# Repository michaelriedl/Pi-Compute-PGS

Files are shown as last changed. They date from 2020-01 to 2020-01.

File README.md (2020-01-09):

# Pi-Compute-PGS
Portable gaming system based on the Raspberry Pi Compute module

I took this project as far as I possibly could but ran out of steam. I figured I would open source it so other people can take it up if they like. The major revisions I was facing are as follows:

1. The buttons need to be moved further away from the screen.
I designed the board independent of designing the enclosure which was a huge mistake. There is not enough clearance around the screen to accomodate a correctly sized button.
2. I ordered the wrong battery IC and ended up frying a prototype board trying to simultaneosy play and charge the PGS.
3. Stereo out
4. HDMI out
5. On-board WiFi

This board was designed in a 4.x version of KiCad and has not been updated to 5.0+ so I'm not sure how it will behave.

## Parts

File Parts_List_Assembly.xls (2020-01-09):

Sub-Assembly | Description | Part | Value | Package | Quantity | Link | Footprint Checked
Pi Compute Module | SODIMM | A114854-ND | - | - | 1 | http://www.digikey.com/product-detail/en/te-connectivity-amp-connectors/1473149-4/A114854-ND/1890696 | Yes
 | Resistor |  | 100k | 0402 | 5 | http://www.digikey.com/product-detail/en/panasonic-electronic-components/ERJ-2RKF1003X/P100KLCT-ND/194127 | Yes
 | Capacitor |  | 4.7uF | 0603 | 2 | http://www.digikey.com/product-detail/en/samsung-electro-mechanics-america-inc/CL10B475KQ8NQNC/1276-2087-1-ND/3890173 | Yes
 | uSD Card Slot | WM6357CT-ND | - | - | 1 | http://www.digikey.com/product-detail/en/molex-llc/1040310811/WM6357CT-ND/2804769 | Yes
 | Micro USB |  | - | - | 1 | http://www.digikey.com/product-detail/en/amphenol-fci/10103594-0001LF/609-4050-1-ND/2350357 | Yes
Power Supplies | Fuse | MF-MSMF200-2CT-ND | 2A | - | 1 | http://www.digikey.com/product-detail/en/bourns-inc/MF-MSMF200-2/MF-MSMF200-2CT-ND/662850 | Yes
 | Capacitor |  | 47uF | 1206 | 6 | http://www.digikey.com/product-detail/en/murata-electronics-north-america/GRM31CR60J476KE19L/490-6508-1-ND/3845705 | Yes
 | Capacitor |  | 100nF | 0402 | 2 | http://www.digikey.com/product-detail/en/kemet/C0402C104K9RACTU/399-4872-1-ND/1090867 | Yes
 | Capacitor |  | 10uF | 0805 | 4 | http://www.digikey.com/product-detail/en/murata-electronics-north-america/GRM219R60J106KE19D/490-3340-1-ND/702881 | Yes
 | Capacitor |  | 1uF | 0402 | 3 | http://www.digikey.com/product-detail/en/taiyo-yuden/JMK105BJ105KV-F/587-1231-1-ND/931008 | Yes
 | Capacitor |  | 4.7uF | 0603 | 1 | http://www.digikey.com/product-detail/en/samsung-electro-mechanics-america-inc/CL10B475KQ8NQNC/1276-2087-1-ND/3890173 | Yes
 | Resistor |  | 0R | 0402 | 2 | http://www.digikey.com/product-detail/en/panasonic-electronic-components/ERJ-2GE0R00X/P0.0JCT-ND/146726 | Yes
 | Resistor |  | 100k | 0402 | 1 | http://www.digikey.com/product-detail/en/panasonic-electronic-components/ERJ-2RKF1003X/P100KLCT-ND/194127 | Yes
 | Inductor |  | 4.7uH 2A | - | 2 | http://www.digikey.com/product-detail/en/bourns-inc/SRN4018-4R7M/SRN4018-4R7MCT-ND/3821520 | Yes
 | Micro USB |  | - | - | 1 | http://www.digikey.com/product-detail/en/amphenol-fci/10103594-0001LF/609-4050-1-ND/2350357 | Yes
 | 3v3 and 1v8 Regul | PAM2306AYPKE | - | - | 1 | http://www.mouser.com/ProductDetail/Diodes-Incorporated/PAM2306AYPKE/?qs=QK%2FAlAnD7r6vC0KF37wC2Q%3D%3D | Yes
 | 2v5 Regul | AP7115-25SEG-7 | - | - | 1 | http://www.mouser.com/ProductDetail/Diodes-Incorporated/AP7115-25SEG-7/?qs=oUsD4qhOtFzl3uIiEMdYbQ%3D%3D | Yes
Screen and Connector | LCD Screen | NHD-4.3-480272EF-ATXL#-ND | - | - | 1 | http://www.digikey.com/product-detail/en/newhaven-display-intl/NHD-4.3-480272EF-ATXL-/NHD-4.3-480272EF-ATXL--ND/3597747 | Yes
 | 40 Pin Connector | WM3431CT-ND | - | - | 1 | http://www.digikey.com/product-detail/en/molex-llc/0541044031/WM3431CT-ND/2405801 | Yes
 | Resistor Array |  | 33R | 1206 | 7 | http://www.digikey.com/product-detail/en/bourns-inc/CAY16-33R0F4LF/CAY16-33R0F4LFDKR-ND/5775070 | Yes
 | Resistor |  | 10k | 0805 | 2 | http://www.digikey.com/product-detail/en/yageo/RC0805FR-0710KL/311-10.0KCRCT-ND/730482 | Yes
 | Resistor |  | 12R | 0805 | 1 | http://www.digikey.com/product-detail/en/yageo/RC0805FR-0712RL/311-12.0CRCT-ND/730514 | Yes
 | Capacitor |  | 10uF | 0805 | 1 | http://www.digikey.com/product-detail/en/murata-electronics-north-america/GRM219R60J106KE19D/490-3340-1-ND/702881 | Yes
 | Capacitor |  | 1uF | 0402 | 2 | http://www.digikey.com/product-detail/en/taiyo-yuden/JMK105BJ105KV-F/587-1231-1-ND/931008 | Yes
 | Capacitor |  | 100nF | 0402 | 1 | http://www.digikey.com/product-detail/en/kemet/C0402C104K9RACTU/399-4872-1-ND/1090867 | Yes
 | Inductor | BRL3225T150K | - | - | 1 | http://www.digikey.com/product-detail/en/taiyo-yuden/BRL3225T150K/587-3027-1-ND/2763398 | Yes
 | Diode | MBR0540 | - | - | 1 | http://www.digikey.com/product-detail/en/fairchild-on-semiconductor/MBR0540/MBR0540CT-ND/3042807 | Yes
 | Diode | SMAZ24-TP | - | - | 1 | https://www.digikey.com/product-detail/en/micro-commercial-co/SMAZ24-TP/SMAZ24-TPMSCT-ND/1636198 | Yes
 | LED Regul | FAN5333BSX | - | - | 1 | http://www.digikey.com/product-detail/en/fairchild-on-semiconductor/FAN5333BSX/FAN5333BSXCT-ND/3042778 | Yes
Game Pad | Right Ang Tact SW |  | - | - | 2 | https://www.digikey.com/product-detail/en/apem-inc/MJTP1117/679-2400-ND/1795496 | Yes
 | Tact SW |  | - | - | 3 | https://www.digikey.com/product-detail/en/e-switch/TL3315NF100Q/EG4620CT-ND/1870400 | Yes
 | Dome SW |  | - | - | 8 | https://www.digikey.com/product-detail/en/keystone-electronics/5133TR/36-5133CT-ND/6834345 | Yes
 | Resistor |  | 10k | 0805 | 13 | http://www.digikey.com/product-detail/en/yageo/RC0805FR-0710KL/311-10.0KCRCT-ND/730482 | Yes
 | Resistor |  | 1k | 0805 | 13 | http://www.digikey.com/product-detail/en/yageo/RC0805FR-071KL/311-1.00KCRCT-ND/730391 | Yes
Battery Management | Charging Controller | MCP73871 | - | - | 1 | https://www.digikey.com/product-detail/en/microchip-technology/MCP73871-2CCI-ML/MCP73871-2CCI-ML-ND/1680971 | Yes
 | Voltage Booster | TPS61090RSAR | - | - | 1 | https://www.digikey.com/product-detail/en/texas-instruments/TPS61090RSAR/296-15259-1-ND/566899 | Yes
 | Capacitor |  | 10uF | 0805 | 2 | http://www.digikey.com/product-detail/en/murata-electronics-north-america/GRM219R60J106KE19D/490-3340-1-ND/702881
 | Capacitor |  | 100nF | 0402 | 1 | http://www.digikey.com/product-detail/en/kemet/C0402C104K9RACTU/399-4872-1-ND/1090867
 | Capacitor |  | 2.2uF | 0603 | 1 | https://www.digikey.com/product-detail/en/yageo/CC0603KRX5R5BB225/311-1449-1-ND/2833755
 | Electrolytic Capacitor |  | 100uF | 1411 | 1 | https://www.digikey.com/product-detail/en/avx-corporation/F930J107KBA/478-8153-1-ND/4005595 | Yes
 | Resistor |  | 1.87M | 0805 | 2 | https://www.digikey.com/product-detail/en/panasonic-electronic-components/ERJ-6ENF1874V/P1.87BTCT-ND/4429149
 | Resistor |  | 340k | 0805 | 1 | https://www.digikey.com/product-detail/en/yageo/RC0805FR-07340KL/311-340KCRCT-ND/730822
 | Resistor |  | 200k | 0805 | 1 | https://www.digikey.com/product-detail/en/yageo/RC0805FR-07200KL/311-200KCRCT-ND/730671
 | Resistor |  | 1k | 0805 | 5 | http://www.digikey.com/product-detail/en/yageo/RC0805FR-071KL/311-1.00KCRCT-ND/730391
 | Resistor |  | 270k | 0805 | 1 | https://www.digikey.com/product-detail/en/yageo/RC0805FR-07270KL/311-270KCRCT-ND/730731
 | Resistor |  | 100k | 0402 | 2 | http://www.digikey.com/product-detail/en/panasonic-electronic-components/ERJ-2RKF1003X/P100KLCT-ND/194127
 | Resistor |  | 15k | 0805 | 1 | https://www.digikey.com/product-detail/en/yageo/RC0805FR-0715KL/311-15.0KCRCT-ND/730555
 | Inductor | ASPI-0615FS-6R8M-T2 | 6.8uH | - | 1 | https://www.digikey.com/product-detail/en/abracon-llc/ASPI-0615FS-6R8M-T2/535-10777-1-ND/2619440 | Yes
 | Transistor | MMUN2133LT1G | - | - | 1 | https://www.digikey.com/product-detail/en/on-semiconductor/MMUN2133LT1G/MMUN2133LT1GOSCT-ND/2705149 | Yes
 | Switch | MHSS1105 | SPDT | - | 1 | https://www.digikey.com/product-detail/en/apem-inc/MHSS1105/679-1849-ND/1949465 | Yes
 | LED |  | - | 1206 | 4 | https://www.digikey.com/product-detail/en/lite-on-inc/LTST-C150GKT/160-1169-1-ND/269241 | Yes
 | Battery Connector |  | - | - | 1 | https://www.digikey.com/product-detail/en/jst-sales-america-inc/S2B-PH-SM4-TB(LF)(SN)/455-1749-1-ND/926846 | Yes
 | Fuse | MF-MSMF200-2CT-ND | 2A | - | 1 | http://www.digikey.com/product-detail/en/bourns-inc/MF-MSMF200-2/MF-MSMF200-2CT-ND/662850 | Yes
Total | SODIMM | A114854-ND | - | - | 1 | http://www.digikey.com/product-detail/en/te-connectivity-amp-connectors/1473149-4/A114854-ND/1890696 |  | U3
 | Resistor |  | 100k | 0402 | 8 | http://www.digikey.com/product-detail/en/panasonic-electronic-components/ERJ-2RKF1003X/P100KLCT-ND/194127 |  | R2, R4, R5, R6, R7, R8, R40, R50
 | Capacitor |  | 4.7uF | 0603 | 3 | http://www.digikey.com/product-detail/en/samsung-electro-mechanics-america-inc/CL10B475KQ8NQNC/1276-2087-1-ND/3890173 |  | C2, C8, C18
 | uSD Card Slot | WM6357CT-ND | - | - | 1 | http://www.digikey.com/product-detail/en/molex-llc/1040310811/WM6357CT-ND/2804769
 | Micro USB |  | - | - | 2 | http://www.digikey.com/product-detail/en/amphenol-fci/10103594-0001LF/609-4050-1-ND/2350357
 | Fuse | MF-MSMF200-2CT-ND | 2A | - | 2 | http://www.digikey.com/product-detail/en/bourns-inc/MF-MSMF200-2/MF-MSMF200-2CT-ND/662850
 | Capacitor |  | 47uF | 1206 | 6 | http://www.digikey.com/product-detail/en/murata-electronics-north-america/GRM31CR60J476KE19L/490-6508-1-ND/3845705 |  | C1, C12, C14, C15, C16, C17
 | Capacitor |  | 100nF | 0402 | 4 | http://www.digikey.com/product-detail/en/kemet/C0402C104K9RACTU/399-4872-1-ND/1090867 |  | C5, C10, C22, C26
 | Capacitor |  | 10uF | 0805 | 7 | http://www.digikey.com/product-detail/en/murata-electronics-north-america/GRM219R60J106KE19D/490-3340-1-ND/702881 |  | C3, C4, C6, C7, C21, C25, C27
 | Capacitor |  | 1uF | 0402 | 5 | http://www.digikey.com/product-detail/en/taiyo-yuden/JMK105BJ105KV-F/587-1231-1-ND/931008 |  | C9, C11, C13, C19, C20
 | Resistor |  | 0R | 0402 | 2 | http://www.digikey.com/product-detail/en/panasonic-electronic-components/ERJ-2GE0R00X/P0.0JCT-ND/146726 |  | R1, R3
 | Inductor |  | 4.7uH 2A | - | 2 | http://www.digikey.com/product-detail/en/bourns-inc/SRN4018-4R7M/SRN4018-4R7MCT-ND/3821520 |  | L1, L2
 | LCD Screen | NHD-4.3-480272EF-ATXL#-ND | - | - | 1 | http://www.digikey.com/product-detail/en/newhaven-display-intl/NHD-4.3-480272EF-ATXL-/NHD-4.3-480272EF-ATXL--ND/3597747
 | 40 Pin Connector | WM3431CT-ND | - | - | 1 | http://www.digikey.com/product-detail/en/molex-llc/0541044031/WM3431CT-ND/2405801
 | Resistor Array |  | 33R | 1206 | 7 | http://www.digikey.com/product-detail/en/bourns-inc/CAY16-33R0F4LF/CAY16-33R0F4LFDKR-ND/5775070
 | Resistor |  | 10k | 0805 | 15 | http://www.digikey.com/product-detail/en/yageo/RC0805FR-0710KL/311-10.0KCRCT-ND/730482 |  | R9, R11, R12, R13, R14, R18, R19, R20, R24, R25, R26, R30, R31, R32, R36
 | Resistor |  | 12R | 0805 | 1 | http://www.digikey.com/product-detail/en/yageo/RC0805FR-0712RL/311-12.0CRCT-ND/730514 |  | R10
 | Inductor | BRL3225T150K | - | - | 1 | http://www.digikey.com/product-detail/en/taiyo-yuden/BRL3225T150K/587-3027-1-ND/2763398 |  | L3
 | Diode | MBR0540 | - | - | 1 | http://www.digikey.com/product-detail/en/fairchild-on-semiconductor/MBR0540/MBR0540CT-ND/3042807 |  | D1
 | Diode | SMAZ24-TP | - | - | 1 | https://www.digikey.com/product-detail/en/micro-commercial-co/SMAZ24-TP/SMAZ24-TPMSCT-ND/1636198 |  | D2
 | LED Regul | FAN5333BSX | - | - | 1 | http://www.digikey.com/product-detail/en/fairchild-on-semiconductor/FAN5333BSX/FAN5333BSXCT-ND/3042778 |  | U5
 | Right Ang Tact SW |  | - | - | 2 | https://www.digikey.com/product-detail/en/apem-inc/MJTP1117/679-2400-ND/1795496
 | Tact SW |  | - | - | 3 | https://www.digikey.com/product-detail/en/e-switch/TL3315NF100Q/EG4620CT-ND/1870400
 | Dome SW |  | - | - | 8 | https://www.digikey.com/product-detail/en/keystone-electronics/5133TR/36-5133CT-ND/6834345
 | Resistor |  | 1k | 0805 | 18 | http://www.digikey.com/product-detail/en/yageo/RC0805FR-071KL/311-1.00KCRCT-ND/730391 |  | R15, R16, R17, R21, R22, R23, R27, R28, R29, R33, R34, R35, R37, R39, R42, R43, R48, R49
 | Charging Controller | MCP73871 | - | - | 1 | https://www.digikey.com/product-detail/en/microchip-technology/MCP73871-2CCI-ML/MCP73871-2CCI-ML-ND/1680971 |  | U7
 | Voltage Booster | TPS61090RSAR | - | - | 1 | https://www.digikey.com/product-detail/en/texas-instruments/TPS61090RSAR/296-15259-1-ND/566899 |  | U6
 | Capacitor |  | 2.2uF | 0603 | 1 | https://www.digikey.com/product-detail/en/yageo/CC0603KRX5R5BB225/311-1449-1-ND/2833755 |  | C23
 | Electrolytic Capacitor |  | 100uF | 1411 | 1 | https://www.digikey.com/product-detail/en/avx-corporation/F930J107KBA/478-8153-1-ND/4005595 |  | C24
 | Resistor |  | 1.87M | 0805 | 2 | https://www.digikey.com/product-detail/en/panasonic-electronic-components/ERJ-6ENF1874V/P1.87BTCT-ND/4429149 |  | R41, R45
 | Resistor |  | 340k | 0805 | 1 | https://www.digikey.com/product-detail/en/yageo/RC0805FR-07340KL/311-340KCRCT-ND/730822 |  | R46
 | Resistor |  | 200k | 0805 | 1 | https://www.digikey.com/product-detail/en/yageo/RC0805FR-07200KL/311-200KCRCT-ND/730671 |  | R44
 | Resistor |  | 270k | 0805 | 1 | https://www.digikey.com/product-detail/en/yageo/RC0805FR-07270KL/311-270KCRCT-ND/730731 |  | R38
 | Resistor |  | 15k | 0805 | 1 | https://www.digikey.com/product-detail/en/yageo/RC0805FR-0715KL/311-15.0KCRCT-ND/730555 |  | R47
 | Inductor | ASPI-0615FS-6R8M-T2 | 6.8uH | - | 1 | https://www.digikey.com/product-detail/en/abracon-llc/ASPI-0615FS-6R8M-T2/535-10777-1-ND/2619440 |  | L4
 | Transistor | MMUN2133LT1G | - | - | 1 | https://www.digikey.com/product-detail/en/on-semiconductor/MMUN2133LT1G/MMUN2133LT1GOSCT-ND/2705149 |  | Q1
 | Switch | MHSS1105 | SPDT | - | 1 | https://www.digikey.com/product-detail/en/apem-inc/MHSS1105/679-1849-ND/1949465
 | LED |  | - | 1206 | 4 | https://www.digikey.com/product-detail/en/lite-on-inc/LTST-C150GKT/160-1169-1-ND/269241
 | Battery Connector |  | - | - | 1 | https://www.digikey.com/product-detail/en/jst-sales-america-inc/S2B-PH-SM4-TB(LF)(SN)/455-1749-1-ND/926846

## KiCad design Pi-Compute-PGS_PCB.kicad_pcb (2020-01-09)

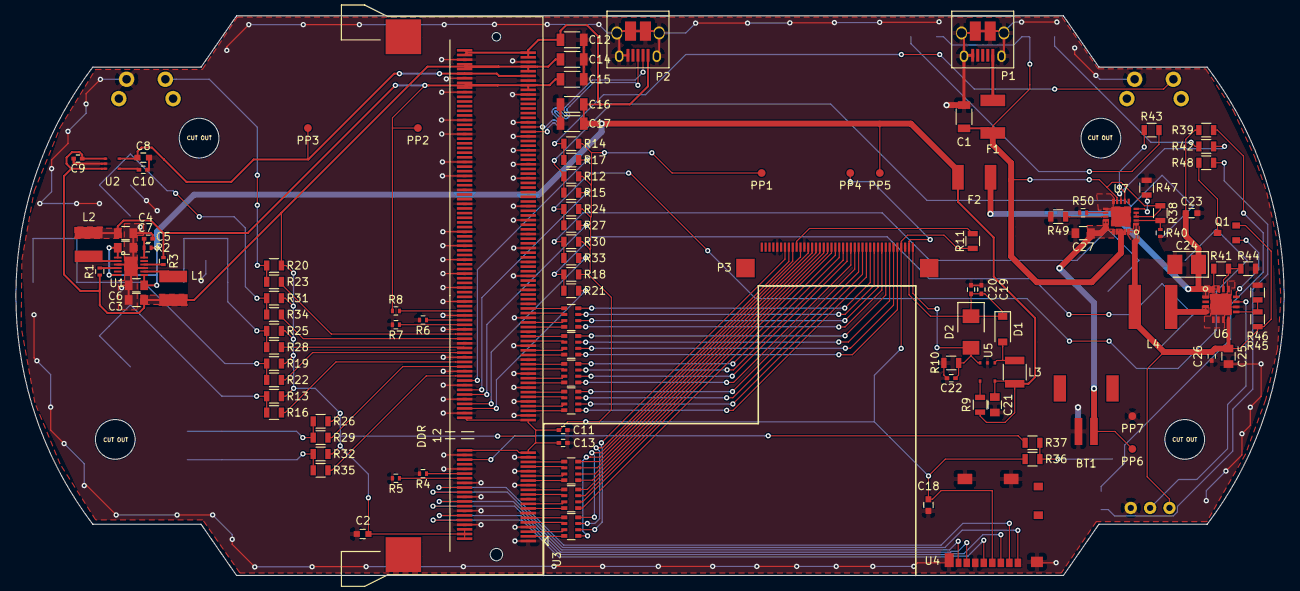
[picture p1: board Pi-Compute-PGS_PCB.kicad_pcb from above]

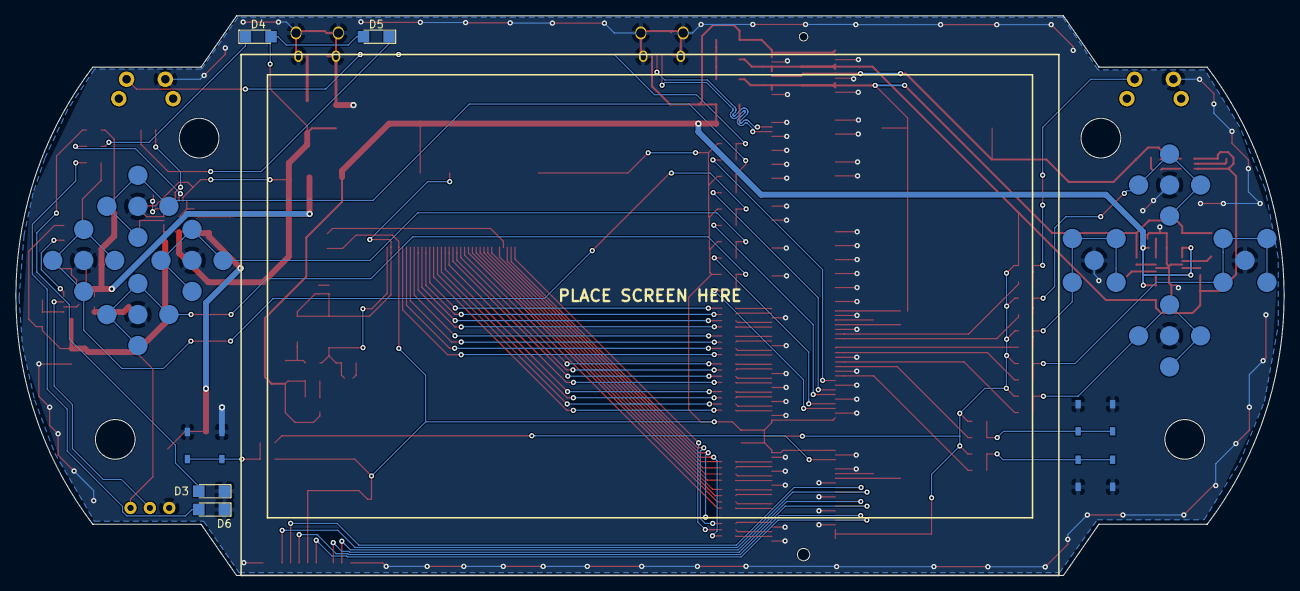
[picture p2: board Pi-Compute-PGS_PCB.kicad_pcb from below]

Board: 2 copper layers, 163.6 x 72.2 mm, 129 parts (15 on the bottom side), 132 nets.

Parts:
BT1: JST 2-PH; JST_2_PH
C1, C12, C14, C15, C16, C17: 47uF; C_1206
C2, C8, C18: 4.7uF; C_0603
C3, C4, C6, C7, C21, C25, C27: 10uF; C_0805
C5, C10, C26: 100nF; C_0402
C9, C11, C13, C19, C20: 1uF; C_0402
C22: 0.1uF; C_0402
C23: 2.2uF; C_0603
C24: 100uF; CP_Tantalum_Case-B_EIA-3528-21_Reflow
D1: MBR0540; D_SOD-123
D2: SMAZ24-TP
D3: Blue; LED_1206
D4: Orange; LED_1206
D5: Green; LED_1206
D6: Red; LED_1206
F1, F2: MF-MSMF200
L1, L2: 4.7uH; SRN4018-4R7M
L3: BRL3225T150K; C_1210
L4: 6.8uH; ASPI-0615FS-6R8M-T2
P1, P2: USB_OTG; USB_Micro-B_10103594-0001LF
P3: 40_Pin_LCD_Out; LCD_Molex_Connector
PP1, PP2, PP3, PP4, PP5, PP6, PP7: Test_Point
Q1: MMUN2133LT1G
R1, R3: 0R; R_0402
R2, R4, R5, R6, R7, R8, R40, R50: 100k; R_0402
R9, R11, R12, R13, R14, R18, R19, R20, R24, R25, R26, R30, R31, R32, R36: 10k; R_0805
R10: 12; R_0805
R15, R16, R17, R21, R22, R23, R27, R28, R29, R33, R34, R35, R37, R39, R42, R43, R48, R49: 1k; R_0805
R38: 270k; R_0805
R41, R45: 1.87M; R_0805
R44: 200k; R_0805
R46: 340k; R_0805
R47: 15k; R_0805
RP1, RP2, RP3, RP4, RP5, RP6, RP7: 33 R_PACK4; R_Array_Convex_4x0603
SW1, SW2: SW_PUSH_SMALL_H; Tact-switch_right_thru_hole
SW3, SW4, SW5, SW6, SW7, SW8, SW9, SW10: SW_PUSH_SMALL_H; Snapdome_SW
SW11, SW12, SW13: SW_PUSH_SMALL_H; E-SW_SMD
U1: PAM2306AYPKE
U2: AP7115-25SEG; AP7115-25SEG-7
U3: DDR2_SODIMM_CM_3_Lite; Socket_SODIMM_DDR2
U4: 1040310811; uSD_1040310811
U5: FAN5333BSX
U6: TPS61090RSAR
U7: MCP73871
U8: SPDT_switch; spdt_switch_MHSS1105

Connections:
1V8: C4.1, C15.1, L2.2, PP2.1, R3.1, R8.2, U3.183, U3.184, U3.185, U3.186
3V3: C2.1, C3.1, C9.1, C11.1, C13.1, C14.1, C18.1, L1.2, P3.4, PP1.1, R1.1, R11.1, R12.2, R13.2, R14.2, R18.2, R19.2, R20.2, R24.2, R25.2, R26.2, R30.2, R31.2, R32.2, R36.2, U2.1, U2.3, U3.2, U3.4, U3.6, U3.39, U3.40, U3.41, U3.42, U3.191, U3.192, U3.193, U3.194, U4.4
5V: C6.1, C7.1, C12.1, C16.1, C17.1, C21.1, F2.1, L3.1, P2.1, PP5.1, R2.1, R9.2, U1.1, U1.6, U1.7, U3.197, U3.198, U3.199, U3.200, U5.5
24V: C19.2, C20.2, D1.1, D2.1, P3.2, PP4.1
A: R16.2, U3.66
A_IN: R13.1, R16.1, SW10.1
B: R22.2, U3.70
B0: RP5.8, U3.15
B1: RP5.7, U3.17
B2: RP5.6, U3.21
B3: RP5.5, U3.23
B4: RP6.8, U3.27
B5: RP6.7, U3.29
B6: RP6.6, U3.33
B7: RP6.5, U3.35
B_IN: R19.1, R22.1, SW7.1
CM_VDAC: C8.1, PP3.1, U2.5, U3.189, U3.190
DE: RP7.7, U3.5
DOWN: R21.2, U3.46
DOWN_IN: R18.1, R21.1, SW9.1
EN_PWR: U6.11, U8.2
G0: RP3.8, U3.45
G1: RP3.7, U3.47
G2: RP3.6, U3.51
G3: RP3.5, U3.53
G4: RP4.8, U3.57
G5: RP4.7, U3.59
G6: RP4.6, U3.63
G7: RP4.5, U3.65
GND: BT1.2, C1.2, C2.2, C3.2, C4.2, C5.2, C6.2, C7.2, C8.2, C9.2, C10.2, C11.2, C12.2, C13.2, C14.2, C15.2, C16.2, C17.2, C18.2, C19.1, C20.1, C21.2, C22.2, C23.2, C24.2, C25.2, C26.2, C27.2, D3.1, D6.1, P1.5, P1.6, P2.5, P2.6, P3.3, P3.29, P3.36, PP7.1, R4.2, R5.2, R6.2, R7.2, R10.1, R40.2, R44.2, R46.2, R47.2, R49.2, R50.2, SW1.2, SW2.2, SW3.2, SW4.2, SW5.2, SW6.2, SW7.2, SW8.2, SW9.2, SW10.2, SW11.2, SW12.2, SW13.2, U1.3, U1.9, U1.13, U2.2, U3.1, U3.7, U3.8, U3.13, U3.14, U3.19, U3.20, U3.25, U3.26, U3.31, U3.32, U3.37, U3.38, U3.43, U3.44, U3.49, U3.50, U3.55, U3.56, U3.61, U3.62, U3.67, U3.68, U3.73, U3.74, U3.79, U3.80, U3.85, U3.86, U3.91, U3.92, U3.97, U3.98, U3.103, U3.104, U3.109, U3.110, U3.115, U3.116, U3.121, U3.122, U3.127, U3.133, U3.134, U3.139, U3.140, U3.145, U3.146, U3.151, U3.152, U3.157, U3.163, U3.164, U3.169, U3.170, U3.181, U3.182, U3.187, U3.188, U3.195, U3.196, U4.6, U4.11, U4.12, U4.13, U4.14, U5.2, U6.5, U6.6, U6.7, U6.10, U6.13, U6.17, U7.10, U7.11, U7.21, U8.1
HOME: R37.2, U3.36
HOME_IN: R36.1, R37.1, SW13.1
HSYNC: RP7.5, U3.11
LEDK: C22.1, D2.2, P3.1, R10.2, U5.3
LEFT: R27.2, U3.52
LEFT_IN: R24.1, R27.1, SW5.1
L_BUMP: R17.2, U3.58
L_BUMP_IN: R14.1, R17.1, SW1.1
unnamed: BT1.1, C27.1, PP6.1, U7.14, U7.15, U7.16
unnamed: C5.1, R2.2, U1.12
unnamed: C10.1, U2.4
unnamed: C23.1, C24.1, F2.2, R39.1, R41.1, U6.1, U6.15, U6.16
unnamed: D1.2, L3.2, U5.1
unnamed: D3.2, R39.2
unnamed: D4.1, R42.1
unnamed: D5.1, R43.1
unnamed: D6.2, R48.2
unnamed: F1.2, P1.1
unnamed: L1.1, U1.8
unnamed: L2.1, U1.2
unnamed: L4.2, U6.3, U6.4
unnamed: P3.5, RP1.1
unnamed: P3.6, RP1.2
unnamed: P3.7, RP1.3
unnamed: P3.8, RP1.4
unnamed: P3.9, RP2.1
unnamed: P3.10, RP2.2
unnamed: P3.11, RP2.3
unnamed: P3.12, RP2.4
unnamed: P3.13, RP3.1
unnamed: P3.14, RP3.2
unnamed: P3.15, RP3.3
unnamed: P3.16, RP3.4
unnamed: P3.17, RP4.1
unnamed: P3.18, RP4.2
unnamed: P3.19, RP4.3
unnamed: P3.20, RP4.4
unnamed: P3.21, RP5.1
unnamed: P3.22, RP5.2
unnamed: P3.23, RP5.3
unnamed: P3.24, RP5.4
unnamed: P3.25, RP6.1
unnamed: P3.26, RP6.2
unnamed: P3.27, RP6.3
unnamed: P3.28, RP6.4
unnamed: P3.30, RP7.1
unnamed: P3.31, R11.2
unnamed: P3.32, RP7.4
unnamed: P3.33, RP7.3
unnamed: P3.34, RP7.2
unnamed: Q1.1, U6.12
unnamed: Q1.3, R48.1
unnamed: R1.2, U1.4
unnamed: R3.2, U1.10
unnamed: R4.1, U3.30
unnamed: R5.1, U3.28
unnamed: R6.1, U3.84
unnamed: R7.1, U3.82
unnamed: R8.1, U3.88
unnamed: R9.1, U5.4
unnamed: R38.2, R40.1, U7.2
unnamed: R41.2, R44.1, U6.14
unnamed: R42.2, U7.8
unnamed: R43.2, U7.7
unnamed: R45.2, R46.1, U6.9
unnamed: R47.1, U7.5
unnamed: R49.1, U7.13
unnamed: R50.1, U7.12
ODCK: RP7.8, U3.3
PWR_IN: C1.1, D4.2, D5.2, F1.1, R38.1, U7.3, U7.4, U7.9, U7.17, U7.18, U7.19
R0: RP1.8, U3.69
R1: RP1.7, U3.71
R2: RP1.6, U3.75
R3: RP1.5, U3.77
R4: RP2.8, U3.81
R5: RP2.7, U3.83
R6: RP2.6, U3.87
R7: RP2.5, U3.89
RIGHT: R33.2, U3.48
RIGHT_IN: R30.1, R33.1, SW6.1
R_BUMP: R23.2, U3.78
R_BUMP_IN: R20.1, R23.1, SW2.1
SDX_CLK: U3.10, U4.5
SDX_CMD: U3.12, U4.3
SDX_D0: U3.16, U4.7
SDX_D1: U3.18, U4.8
SDX_D2: U3.22, U4.1
SDX_D3: U3.24, U4.2
SELECT: R35.2, U3.60
SELECT_IN: R32.1, R35.1, SW12.1
START: R29.2, U3.64
START_IN: R26.1, R29.1, SW11.1
UP: R15.2, U3.54
UP_IN: R12.1, R15.1, SW3.1
USB_D+: P2.3, U3.165
USB_D-: P2.2, U3.167
VBAT: C25.1, C26.1, L4.1, Q1.2, R45.1, U6.8, U7.1, U7.20, U8.3
VSYNC: RP7.6, U3.9
X: R28.2, U3.72
X_IN: R25.1, R28.1, SW8.1
Y: R34.2, U3.76
Y_IN: R31.1, R34.1, SW4.1
